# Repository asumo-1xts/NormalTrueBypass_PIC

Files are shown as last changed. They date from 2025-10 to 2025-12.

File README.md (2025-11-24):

<h1 align="center">
NormalTrueBypass_PIC
</h1>

<div align="center">

**A project for a true-bypass with an DIP8 PIC microcontroller.**









</div>

## Features

- Selectable operating mode: Alternate or Momentary
- Set the power-on state: ON or OFF
- (Option) Selectable timing to switch: when-pressed or when-released
- Automatically bypasses if power is accidentally turned off

## Verified on

- PIC12F629
- PIC12F675
- PIC12F1822

## dir: `KiCad`

KiCad関連のファイル一式です。

ガーバーファイルは[Release](https://github.com/asumo-1xts/NormalTrueBypass_PIC/releases)からダウンロードできます。

## dir: `src`

PICマイコン用のソースコード群です。

プロジェクト管理の様式はVScode用のMPLAB Extension Packに準拠しています。

コンパイル後のhexファイルは[Release](https://github.com/asumo-1xts/NormalTrueBypass_PIC/releases)からダウンロードできます。

PICマイコン間で共通のソースコードは`src`直下に、そうでないものはそのハードウェアの名前の付いたディレクトリに入っています。

`src/header.h`の冒頭で所望のPICマイコンのヘッダーファイルをincludeするだけで、そのPICマイコンが書き込み対象となります。

## `write_hex.*`

書き込みはコマンドラインで完結できます。

以下はPICKIT3でPIC12F675に書き込む際の例です。

### Debian 13 (and some other Linux distributions)

```shell
cd /opt/microchip/mplabx/v6.20/mplab_platform/mplab_ipe

sudo sh ipecmd.sh \
--% -P12F675 -TPPK3 -M \
-F"/home/asumo/Remote/NormalTrueBypass_PIC/out/PIC12F675/default.hex"
```

### Windows 11

```powershell
& "C:\Program Files\Microchip\MPLABX\v6.20\mplab_platform\mplab_ipe\ipecmd.exe" --% -P12F675 -TPPK3 -M -F"C:\Users\asumo\MPLABProjects\Lchica\out\Lchica\default.hex"
```

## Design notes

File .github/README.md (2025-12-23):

<h1 align="center">
NormalTrueBypass_PIC
</h1>

<div align="center">

**A project for a true-bypass with an DIP8 PIC microcontroller.**









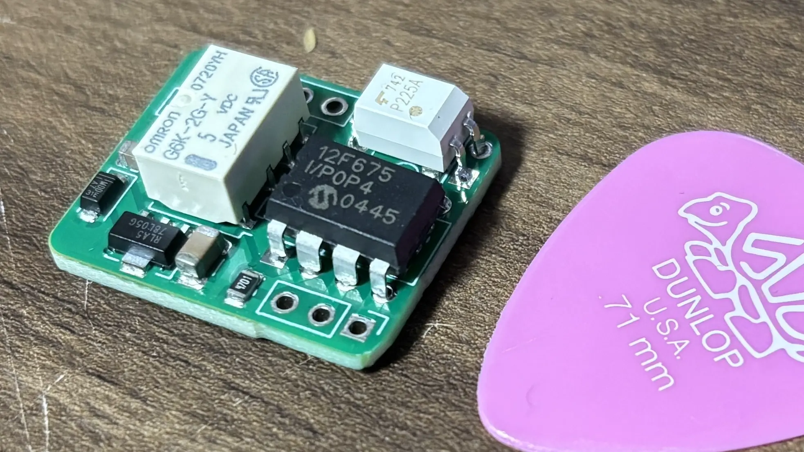
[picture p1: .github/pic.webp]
Actual board


</div>

## Features

- Selectable operating mode: Alternate or Momentary
- Selectable power-on state: ON or OFF
- Selectable timing to switch: When-pressed or When-released
- Automatically bypasses if power is accidentally turned off

## Verified on

- PIC12F629
- PIC12F675
- PIC12F1822

## dir: `KiCad`

KiCad関連のファイル一式です。

ガーバーファイルは[Release](https://github.com/asumo-1xts/NormalTrueBypass_PIC/releases)からダウンロードできます。

## dir: `src`

PICマイコン用のソースコード群です。

プロジェクト管理の様式はVScode用のMPLAB Extension Packに準拠しています。

コンパイル後のhexファイルは[Release](https://github.com/asumo-1xts/NormalTrueBypass_PIC/releases)からダウンロードできます。

PIC マイコン間で共通のソースコードは`src`直下に、そうでないものはそのハードウェアの名前の付いたディレクトリに入っています。

`src/header.h`の冒頭で所望のPICマイコンのヘッダーファイルをincludeするだけで、そのPICマイコンが書き込み対象となります。

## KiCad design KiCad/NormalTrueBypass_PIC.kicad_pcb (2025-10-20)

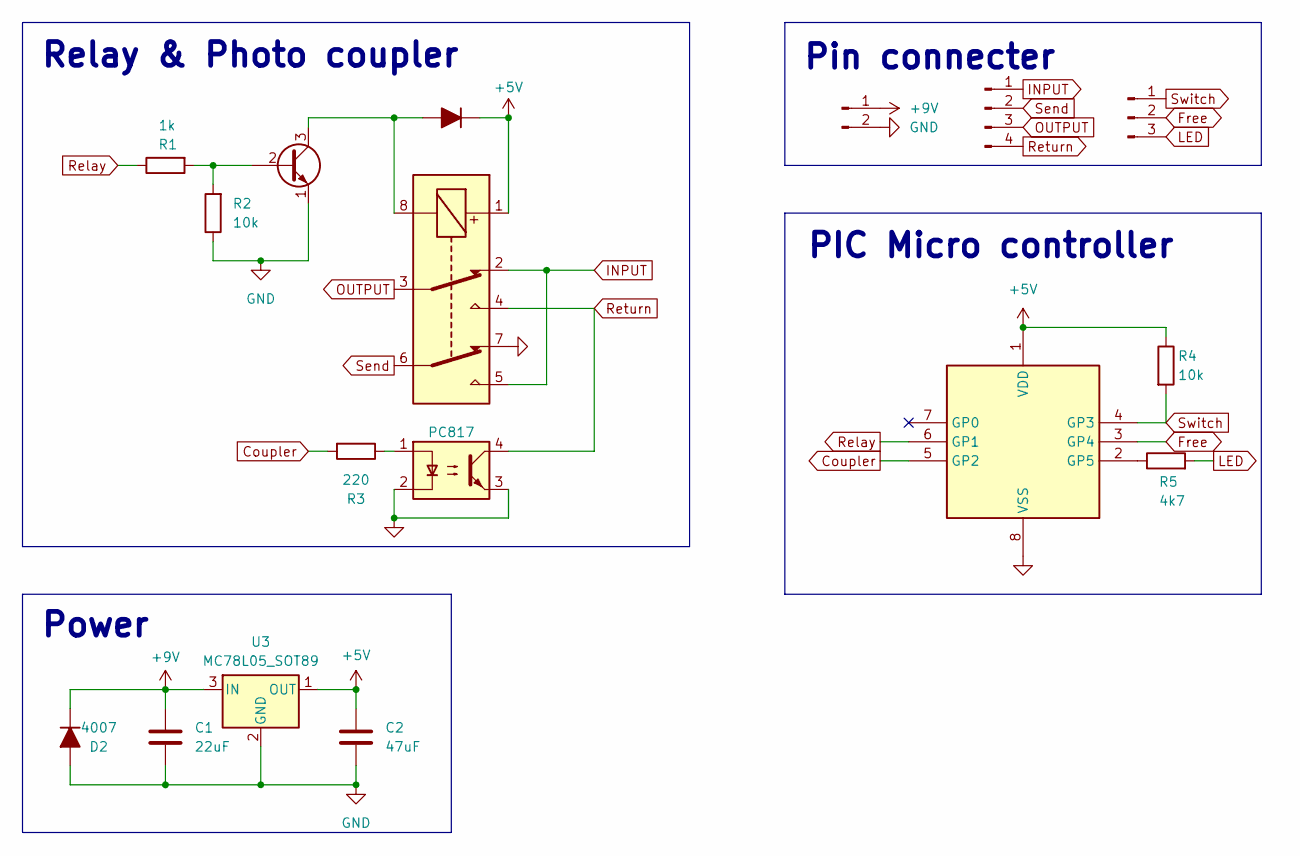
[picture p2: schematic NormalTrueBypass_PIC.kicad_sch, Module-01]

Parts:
C1: 22uF; C_0805_2012Metric
C2: 47uF; C_1206_3216Metric
D1: CD4148W; D_SOD-323
D2: 4007; D_SOD-323
J1: Conn_01x07_Pin; PinHeader_1x02_P2.54mm_Vertical
J2: Conn_01x07_Pin; PinHeader_1x04_P2.54mm_Vertical
J3: Conn_01x07_Pin; PinHeader_1x03_P2.54mm_Vertical
K1: Relay; Relay_DPDT_Omron_G6K-2G-Y
Q1: 2N3904; SOT-23
R1: 1k; R_0805_2012Metric
R2, R4: 10k; R_0805_2012Metric
R3: 220; R_0805_2012Metric
R5: 4k7; R_0805_2012Metric
U1: PC817; DIP-4_W7.62mm
U2: PIC12F675-xP; DIP-8_W7.62mm
U3: MC78L05_SOT89; SOT-89-3

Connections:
+5V: C2.1, D1.1 (K), K1.1, R4.1, U2.1 (VDD), U3.1 (OUT)
+9V: C1.1, D2.1 (K), J1.1, U3.3 (IN)
Coupler: R3.2, U2.5 (GP2)
Free: J3.2, U2.3 (GP4)
GND: C1.2, C2.2, D2.2 (A), J1.2, K1.7, Q1.1 (E), R2.1, U1.2, U1.3, U2.8 (VSS), U3.2 (GND)
INPUT: J2.1, K1.2, K1.5
LED: J3.3, R5.2
unnamed: D1.2 (A), K1.8, Q1.3 (C)
unnamed: Q1.2 (B), R1.2, R2.2
unnamed: R3.1, U1.1
unnamed: R5.1, U2.2 (GP5)
OUTPUT: J2.3, K1.3
Relay: R1.1, U2.6 (GP1)
Return: J2.4, K1.4, U1.4
Send: J2.2, K1.6
Switch: J3.1, R4.2, U2.4 (GP3)

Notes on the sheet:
Pin connecter
PIC Micro controller
Relay & Photo coupler
Power

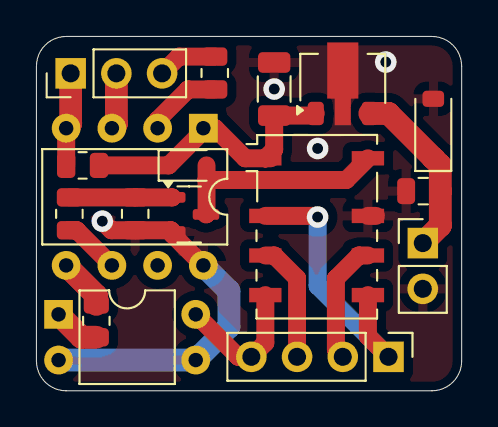
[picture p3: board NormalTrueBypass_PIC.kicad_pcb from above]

Board: 2 copper layers, 23.6 x 19.7 mm, 17 parts (0 on the bottom side), 16 nets.

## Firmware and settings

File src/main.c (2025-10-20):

/**
 * @file        main.c
 * @author      aSumo
 * @version     2.0
 * @date        2025-05-04
 * @copyright   (c) 2024 aSumo
 * @brief       Program for Normal True Bypass with PIC microcontroller.
 * @details
 * header.hにてincludeするファイルを変更するだけで対象のデバイスを切り替えられます。
 */

#include "header.h"

/**
 * @fn      void main(void)
 * @brief   サボり上司
 * @details
 * スキャン式か割り込み式を選択できます。この選択はmain関数内で統一しなければなりません。
 */
int main(void) {
  // init_scan();
  // bypass_scan();
  // or
  init_interrupt();
  bypass_interrupt();

  return 0;
}

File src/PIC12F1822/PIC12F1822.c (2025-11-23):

/**
 * @file        PIC12F1822.c
 * @author      aSumo
 * @version     1.0
 * @date        2025-05-12
 * @copyright   (c) 2025 aSumo
 * @details     PIC12F1822用の関数を定義するファイル
 */

#include "PIC12F1822.h"

#include "../header.h"

//! EEPROM（0x00~0x07）の初期値を定義するマクロ
__EEPROM_DATA(0, 0, 0, 0, 0, 0, 0, 0);

// EEPROMから読み込むグローバル変数
// ここは本当に仮の値で、初期値はEEPROMに設定することで変更できる（main.c）
bool initState = false;  //!< ペダルの初期状態
bool momentary = false;  //!< モーメンタリ動作の是非
bool timing = false;  //!< オルタネイト動作時、いつ反転するか

/**
 * @fn      uint8_t eepRead(uint8_t adress)
 * @brief   EEPROMからデータを読み込む関数
 * @param   adress  データを読み込む番地
 * @return  読み込んだデータ
 */
uint8_t eepRead(uint8_t address) {
  EEADR = address;    // Set EEPROM address
  EECON1bits.RD = 1;  // Begin EEPROM read
  while (EECON1bits.RD) {
    ;
  }  // Wait for read to complete
  return EEDATA;  // Return the data byte read
}

/**
 * @fn      uint8_t eepWrite(uint8_t adress, uint8_t myData)
 * @brief   EEPROMにデータを書き込む関数
 * @param   adress  データの書き込み番地
 * @param   myData  書き込むデータ（少なくとも数値型であること！）
 */
void eepWrite(uint8_t address, uint8_t myData) {
  EECON1bits.WREN = 1;  // Enable EEPROM writes
  EEADR = address;      // Set EEPROM address
  EEDATA = myData;      // Load data to write
  // Required unlock sequence
  EECON2 = 0x55;
  EECON2 = 0xAA;
  EECON1bits.WR = 1;  // Trigger write
  while (EECON1bits.WR) {
    ;
  }  // Wait for write to finish
  EECON1bits.WREN = 0;  // Disable writes
}

/**
 * @fn      void init_scan(void)
 * @brief   諸々の初期化を行う関数（スキャン式）
 */
void init_scan(void) {
  disAnalog();  // Disable ADC/analog comparators
  CM1CON0 = 0x00;
#ifdef CM2CON0
  CM2CON0 = 0x00;  // Disable Comparator 2 (if present)
#endif
  OSCCON = 0b01111000;  // 内部クロックを16 MHz に設定
  TRISA = 0x08;         // RA3 (foot switch) as input, all others as output
  LATA = 0x00;          // Set all outputs LOW

  setInitState();  // Set initial state based on EEPROM values
}

/**
 * @fn      void init_scan(void)
 * @brief   諸々の初期化を行う関数（割り込み式）
 * @details init_scanとほぼ同じだが、割り込みを有効にするための設定を行う
 */
void init_interrupt(void) {
  disAnalog();
  CM1CON0 = 0x00;
#ifdef CM2CON0
  CM2CON0 = 0x00;
#endif
  OSCCON = 0b01111000;  // 内部クロックを16 MHz に設定
  TRISA = 0x08;         // RA3 input, others output
  LATA = 0x00;          // All outputs LOW

  // Enable interrupt-on-change on RA3 (foot switch pin)
  INTCONbits.IOCIE = 1;  // Enable IOC (pin change) interrupts
  IOCAP = 0x08;          // Interrupt on rising edge of RA3
  IOCAN = 0x08;          // Interrupt on falling edge of RA3
  di();                  // Disable global interrupts until ready (XC8 macro)

  setInitState();
}

/**
 * @fn      void __interrupt isr(void)
 * @brief   bypass_interrupt()の無限whileループ中に呼び出される
 * @details 割り込み処理の中で関数を呼ぶとあんまり良くないらしい
 * @n       参考:
 * https://developerhelp.microchip.com/xwiki/bin/view/software-tools/xc8/non-reentrant/
 */
void __interrupt() isr(void) {
  if (INTCONbits.IOCIF) {  // If an interrupt-on-change occurred
    insideISR();
    IOCAFbits.IOCAF3 = 0;
    INTCONbits.IOCIF = 0;
  }
}

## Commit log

2025-11-23 dev: From Win11 to Debian13 (#2)
    * update: Immigrate from Win11 to Debian13
    * update: write_hexコマンドを明示
2025-11-23 fix: フォトカプラの応答時間を修正 (#4)
2025-11-23 feat: 自動フォーマッタを導入 (#8)
2025-11-23 docs: READMEを編集 (#9)
2025-11-24 docs: READMEを編集 (#11)
2025-11-24 delete: 不要な設定を削除 (#12)
2025-11-24 move: READMEをルートから移動 (#13)
2025-12-10 move: .clang-formatを移動 (#15)
2025-12-10 update: zsh-autoenvを導入
2025-12-12 dev: 開発環境の整備 (#18)
    * move: .clang-formatをルートへ再移動
    * update: 拡張機能に関する整備
2025-12-18 feat: タスクランナーとしてmiseを導入 (#19)
2025-12-23 docs: READMEを更新 (#20)
    * update: 英単語の前後の空白を削除
    * add: 実際の基板の写真を追加
